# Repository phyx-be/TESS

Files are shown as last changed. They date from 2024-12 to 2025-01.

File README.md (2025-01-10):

# TESS
## TESS
TESS is an Adafruit Feather compatible embedded Linux board based on the Allwinner T113-S3 SoC with 128MB of DDR3 RAM built-in. We did add some pins that are not in the original spec, these allow for USB and debug UART to be available on regular pinheaders. This SoC does however only have 1 ADC pin availble that is even limited to 1.8V, so the extra analog pins are replaced by digital pins with various mux options. Allowing for multiple I²C busses, UARTs and CAN interfaces to be used.
Some key features of TESS REV 00 are:
- [Allwinner T113-S3 SoC](https://linux-sunxi.org/T113-s3) with dual core Cortex A7 running at 1.2GHz and 128 MB DDR3 RAM
- 512 MB SD-storage soldered down
- [ESP32-C3-MINI-1](https://www.espressif.com/en/module/esp32-c3-mini-1-en) Wi-Fi and Bluetooth module
- battery charger (up to 1.2A selectable in software)
- Microphone
- 3 user LEDs
- [RPI Touch Display 2](https://www.raspberrypi.com/products/touch-display-2/) compatible DSI connector

## Software
Follow the development of our [buildroot Linux.](https://github.com/phyx-be/buildroot-tess)

## Blockdiagram
TESS is designed to be a breakout board for the Allwinner T113-S3 with limited features on the board but maximal flexibility.
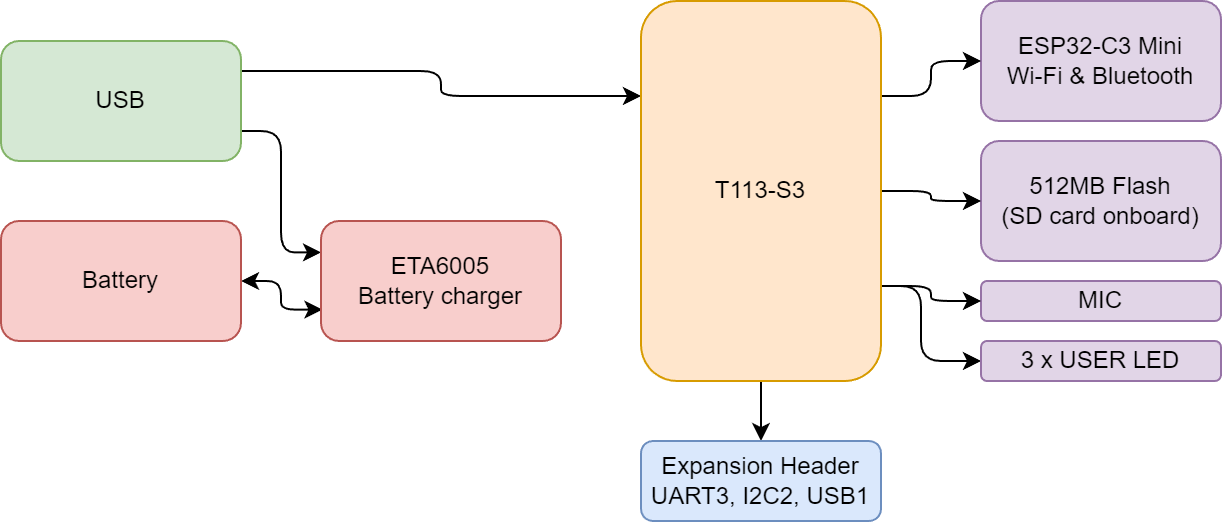
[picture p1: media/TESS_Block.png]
TESS 00 Blockdiagram


## Power
TESS has a 3.3V and 0.9V DC-DC regulator onboard whilst the T113-S3 has 2 LDO's built-in for the 1.8V and 1.5V rails.
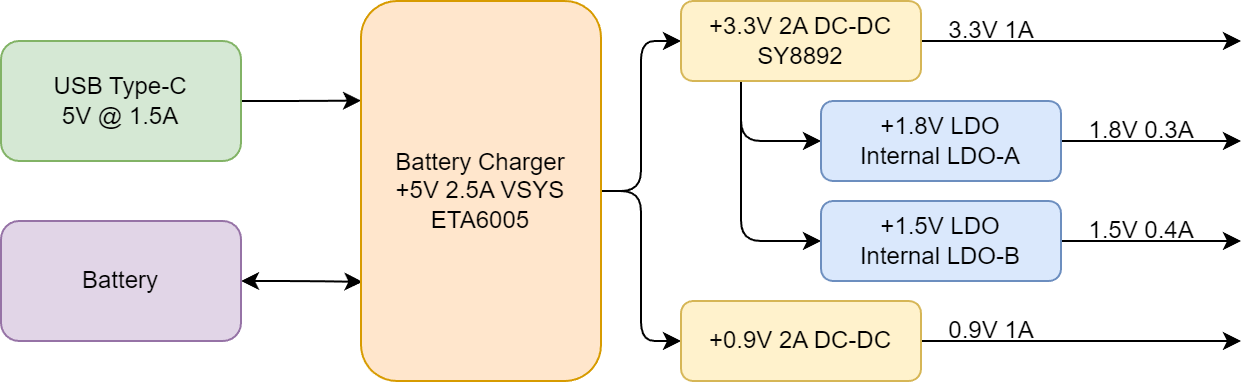
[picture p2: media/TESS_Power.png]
TESS 00 pinout


## Pinout
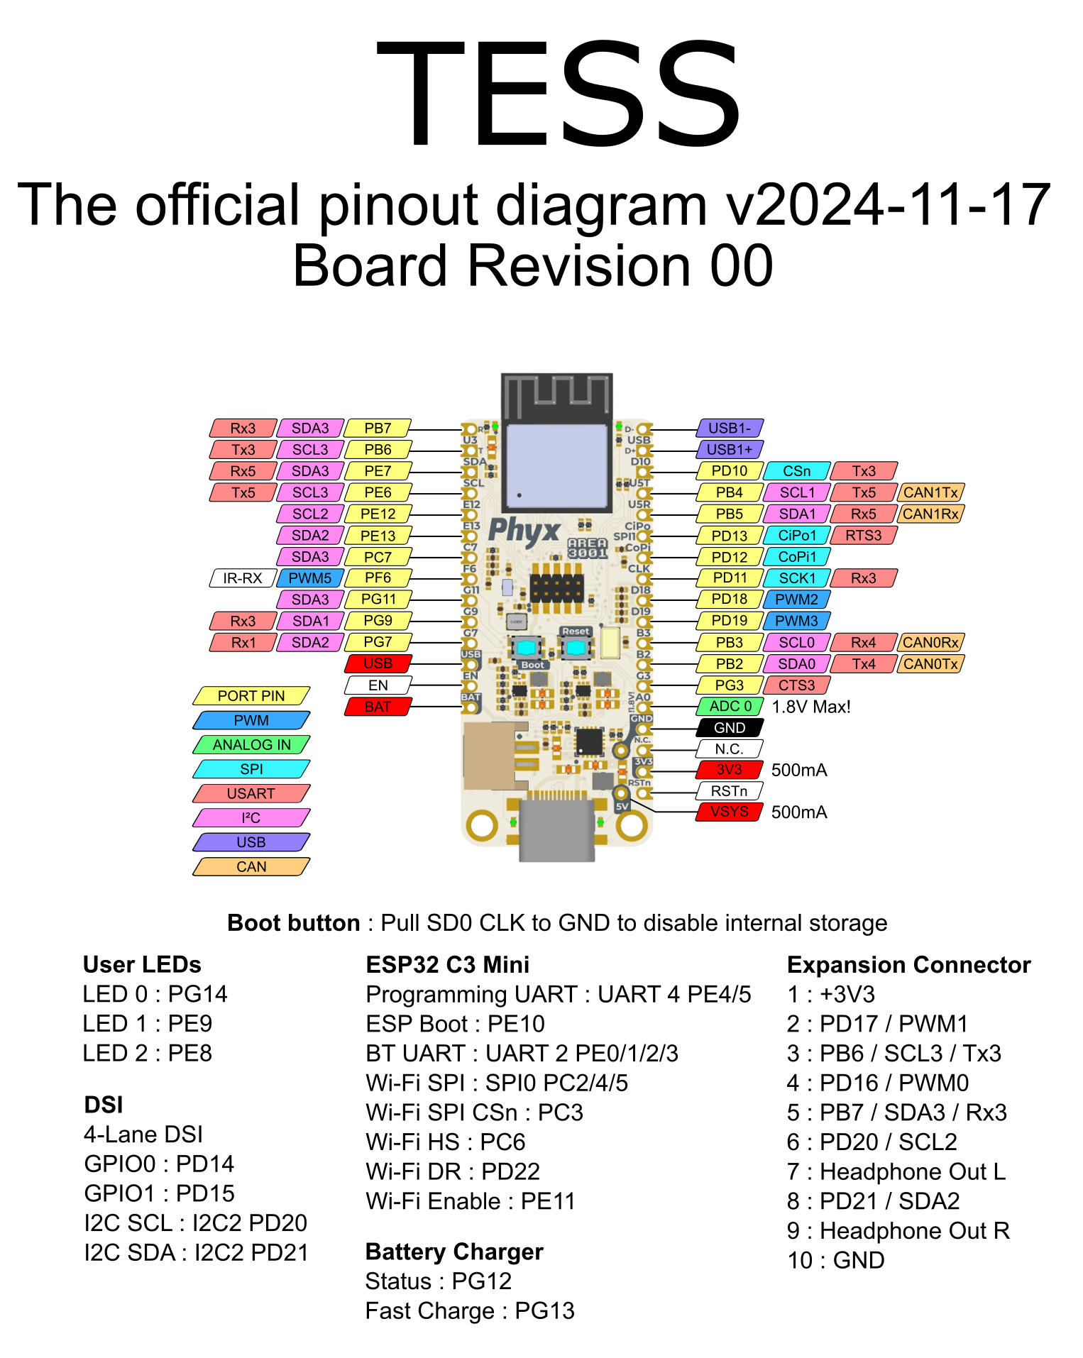
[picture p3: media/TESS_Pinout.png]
TESS 00 pinout


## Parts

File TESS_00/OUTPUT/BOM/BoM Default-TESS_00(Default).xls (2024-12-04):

Bill of Materials |  |  | Tess
Project: |  | TESS_00.PrjPcb
Revision: |  | 00
Variant: |  | Default
Creation Date: | 13/11/2024 | 21:49
Print Date: | 2024-11-15 | 11:54:10
Footprint | Comment | LibRef | Designator | Value | Description | Supplier 1 | Supplier Part Number 1 | Supplier 2 | Supplier Part Number 2 | Supplier 3 | Supplier Part Number 3 | Quantity
C0402 |  | CAP # 10pF 50V 0402 | C1, C2, C3, C4, C41, C42 | 10pF | CAP # 10pF 50V 0402 |  |  |  |  | Generic | 10pF 0402 | 6
C0603_N |  | CAP # 22uF 6.3V 0603 X5R | C5, C31, C34, C35, C38, C39, C43, C44, C45, C46 | 22uF 6V3 | CAP # 22uF 6.3V 0603 X5R | LCSC | C6119880 | LCSC | C159801 | LCSC | C59461 | 10
C0402 |  | CAP # 100nF 50V 0402 | C6, C7, C8, C9, C12, C13, C16, C17, C18, C19, C20, C25, C26, C27, C28, C29, C32, C36, C40, C48, C49, C50, C51, C52, C53, C59, C60 | 100nF 50V | CAP # 100nF 50V 0402 | Farnell | 3013345 | LCSC | C131394 | Generic | 100nF 50V 0402 X7R | 27
C0402 |  | CAP # 10uF 6V3 0402 | C10, C22, C30, C33, C37, C47 | 10uF 6V3 | CAP # 10uF 6V3 0402 | LCSC | C15525 | LCSC | C87148 | Generic | 10uF 6V3 0402 X5R | 6
C0402 |  | CAP # 2u2F 6V3 0402 | C11, C14, C15, C23, C24 | 2u2F 6V3 | CAP # 2u2F 6V3 0402 | LCSC | C12530 |  |  | Generic | 2u2F 6V3 0402 X5R | 5
C0402 |  | CAP # 1uF 10V 0402 | C21 | 1uF 10V | CAP # 1uF 10V 0402 | LCSC | C380293 |  |  | Generic | 1uF 10V 0402 X5R | 1
LED_0402_GR | Default 0402 Green LED | LED # Green 0402 | D1, D2, D3, D4 |  | LED # Green 0402 | LCSC | C434449 | LCSC | C25503345 |  |  | 4
XUNPU-TYPEC-304S-ACP16 | USB 2.0 C Reversible Receptacle Horizontal full SMD | USB # C 2.0 RCPT TYPEC-304S-ACP16 | J1 | TYPEC-304S-ACP16 | USB # C 2.0 RCPT TYPEC-304S-ACP16 | LCSC | C5187472 | LCSC | C2927040 | LCSC | C5156603 | 1
SUN_0806 | WPN201610H1R0MTY01 | IND # 2u2H 2.2A WPN201610H1R0MTY01 0806 | L1, L2 | 2u2H | IND # 2u2H 2.2A WPN201610H1R0MTY01 0806 | LCSC | C97003 |  |  |  |  | 2
SUN_1008 | WPN252012H2R2MT | IND # 2u2H 1.9A WPN252012H2R2MT 1008 | L3 | 2u2H | IND # 2u2H 1.9A WPN252012H2R2MT 1008 | LCSC | C98350 |  |  |  |  | 1
ESP-ESP32-Cx-MINI-1 | ESP32-C3 based MINI-1 4MB Flash | WiFi # MOD ESP32-C3-MINI-1-N4 | MOD1 | ESP32-C3-MINI-1-N4 | WiFi # MOD ESP32-C3-MINI-1-N4 | LCSC | C2838502 | Digi-key | 1965-ESP32-C3-MINI-1-N4CT-ND |  |  | 1
WE_620102131822 | Header 2.0mm Shrouded 2 | HDR # SHR 2.0mm 2way - 620102131822 | P1 | 620102131822 | HDR # SHR 2.0mm 2way - 620102131822 | Wurth | 620102131822 | Mouser | 710-620102131822 |  | C2888424 | 1
JUS_FC05-S22DCU-00 | 22 way 0.5mm Horizontal Top Contact ZIF | ZIF # 0.5mm H Top 22 way - FC05-S22DCU-00 | P4 | FC05-S22DCU-00 | ZIF # 0.5mm H Top 22 way - FC05-S22DCU-00 | LCSC | C2998855 | LCSC | C11091 |  |  | 1
HDR2X5_1.27_SMD | Header 5x2 | Pin Header # 1.27mm dual row 10way | P5 |  | Pin Header # 1.27mm dual row 10way | Farnell | 1022310 | Wurth | 621 010 210 21 |  |  | 1
R0402 |  | RES # 5K1 0402 | R1, R2 | 5K1 | RES # 5K1 0402 | LCSC | C274895 |  |  | Generic | 5K1 1% 0402 | 2
R0402 |  | RES # 100K 0402 | R3, R10, R13, R18, R19, R29 | 100K | RES # 100K 0402 | Farnell | 1358096 |  |  | Generic | 100K 1% 0402 | 6
R0402 |  | RES # 4K7 0402 | R4, R5, R6, R7, R8, R9, R11, R12, R23, R24, R33, R35, R36, R38, R39 | 4K7 | RES # 4K7 0402 |  |  |  |  | Generic | 4K7 1% 0402 | 15
R0402 |  | RES # 10K 0402 | R14, R20, R21, R22, R25, R28, R37 | 10K | RES # 10K 0402 | Farnell | 1358069 |  |  | Generic | 10K 1% 0402 | 7
R0402 |  | RES # 2K2 0402 | R15, R27 | 2K2 | RES # 2K2 0402 |  |  |  |  | Generic | 2K2 1% 0402 | 2
R0402 |  | RES # 22R 0402 | R16 | 22R | RES # 22R 0402 | Farnell | 1357998 |  |  | Generic | 22R 1% 0402 | 1
R0402 |  | RES # 0R 0402 | R17 | 0R | RES # 0R 0402 | Farnell | 2072513 |  |  | Generic | 0R 1% 0402 | 1
R0402 |  | RES # 820R 0402 | R26 | 820R | RES # 820R 0402 |  |  |  |  | Generic | 820R 1% 0402 | 1
R0402 |  | RES # 240R 0402 | R30, R40 | 240R | RES # 240R 0402 | LCSC | C114755 | LCSC | C25094 | Generic | 240R 1% 0402 | 2
R0402 |  | RES # 75R 0402 | R31 | 75R | RES # 75R 0402 | LCSC | C103159 | LCSC | C168249 | Generic | 75R 1% 0402 | 1
R0402 |  | RES # 33R 0402 | R32, R34 | 33R | RES # 33R 0402 |  |  |  |  | Generic | 33R 1% 0402 | 2
WE_434153017835 | LP SMD tact sw WS-TASV | SW # TACT mini 3.5x2.9 mm SMD J-Bend WS-TASV | SW1, SW2 | 434153017835 | SW # TACT mini 3.5x2.9 mm SMD J-Bend WS-TASV | Wurth | 434153017835 | Mouser | 710-434153017835 | LCSC | C33129656 | 2
TQFP_128_14.0x14.0_P0.4_5.7x5.7EP | 2 x A7 1GHz, 128MB DDR3 | A7 # T113-S3 | U1 | T113-S3 | A7 # T113-S3 | LCSC | C5197687 |  |  |  |  | 1
ZET_LGA8 | SD Card chip 2.7V~3.6V 4Gbit LGA-8(6x8) NAND FLASH | FLSH SD # 4Gb ZDSD04GLGEAG | U2 | ZDSD04GLGEAG | FLSH SD # 4Gb ZDSD04GLGEAG | LCSC | C2875854 | LCSC | C5349318 |  |  | 1
SIL_SOT563 | 2.5~5.5Vin 2A SOT563 SY8892 | PWR # BUCK SY8892 2A | U3, U4 | SY8892 | PWR # BUCK SY8892 2A | LCSC | C3151908 |  |  |  |  | 2
QFN_16_3X3_P0.5_1.65X1.65EP | 2.5A 3MHz DCDC Li-Ion charger | PWR # BOOST CHG 2.5A ETA6005Q3Q | U5 | ETA6005Q3Q | PWR # BOOST CHG 2.5A ETA6005Q3Q | LCSC | C7436030 |  |  |  |  | 1
LIN_LMA3722T421-OA5 | Omni-directional -42dB 300Ω 55dB SMD-4P,3.8x2.2mm MEMS Microphones | MIC # MEMS ANA LMA3722T421-OA5 | U6 | LMA3722T421-OA5 | MIC # MEMS ANA LMA3722T421-OA5 | LCSC | C5373233 |  |  |  |  | 1
XTAL_2012 | 32.768Khz 2012 12.5pF | XTAL # 32.768kHz 12.5pF 2012 | Y1 | 32.768kHz | XTAL # 32.768kHz 12.5pF 2012 | LCSC | C5271201 | LCSC | C97607 | LCSC | C403709 | 1
XTAL_2520 | 24MHz 2520 9pF 10ppm | XTAL # 24MHz 9pF 2520 10ppm | Y2 | 24MHz | XTAL # 24MHz 9pF 2520 10ppm | LCSC | C7294625 |  |  |  |  | 1
 |  |  |  |  |  |  |  |  |  |  |  | 117
Approved |  | Notes

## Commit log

2026-11-11 Add the Buildroot external tree
    buildroot-external/ is the BR2_EXTERNAL tree for the Tess images: the
    A/B main image with RAUC (tess_defconfig), the USB flasher image
    (tess_flasher_defconfig), the board files and the ESP32-C3 firmware
    build. It builds on the phyxbe-tess branch of
    https://github.com/phyx-be/buildroot-tess, which adds the board
    support (device tree, U-Boot fragment, minimal defconfig) meant for
    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
2026-11-11 buildroot-external: U-Boot default environment file, merged overlays, common fragment
    - The A/B boot environment of the main image is no longer a U-Boot
    patch (board/sunxi/tess.env through CONFIG_ENV_SOURCE_FILE) but the
    text file board/tess/uboot/tess-main.env, used as the complete default
    environment with BR2_TARGET_UBOOT_DEFAULT_ENV_FILE. As that replaces
    the whole built-in environment, the file also carries bootcmd and the
    sunxi load addresses that sysboot/extlinux need.
    - The root filesystem overlays move under board/tess/rootfs_overlay/:
    common (both images), main and flasher.
    - The U-Boot fragment shared by both images (device tree overlays) is
    board/tess/uboot/tess-comm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
2026-11-11 buildroot-external: build the display overlay as a .dtb, drop the kbuild patch
    Linux 6.18 cannot build a single .dtbo in arch/arm/boot/dts, where
    Buildroot copies custom device trees: that directory has no dtb-y, so
    kbuild does not include the %.dtbo rule. Instead of patching kbuild,
    name the overlay source rpi-7inch-dsi-overlay.dts and let the kernel
    build it with its %.dtb rule; the result, rpi-7inch-dsi-overlay.dtb,
    is an overlay all the same (checked: __symbols__ and __fixups__
    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
2026-11-11 buildroot-external: Buildroot as a git submodule
    buildroot-external/buildroot is a submodule of the phyxbe-tess branch of
    https://github.com/phyx-be/buildroot-tess, pinned to the commit that
    adds the board support, instead of a checkout the user has to create.
    The READMEs explain cloning with submodules and moving the submodule
    after a rebase of the branch.
2026-11-11 buildroot-external: take the kernel and U-Boot hashes from the in-tree board directory
    BR2_GLOBAL_PATCH_DIR lists Buildroot's board/phyxbe/tess/patches before
    the external patch directory, so the hash files of Linux 6.18.8, its
    headers and U-Boot 2026.01 that the board support commit carries are
    used, and the copies here go. Buildroot looks for
    <dir>/<package>/<package>.hash in every global patch directory.
2026-11-11 buildroot-external: make targets for both images and flashing, flash.sh at the top
    external.mk gets tess-main, tess-flasher (builds the main image first,
    as the flasher embeds it) and tess-flash, usable from any configured
    output directory: make -C output-flasher tess-flasher. tess-flash first
    runs sunxi-fel version to check that the board is in FEL. flash.sh, a
    host tool rather than a board file, moves to the top of the tree.
2026-11-11 buildroot-external: kernel fragments in board/tess/linux/
    Kernel configurations are checked to come out identical.
2026-11-11 buildroot-external: flasher on the USB serial console, like the main image
    Nothing in the flasher used its CDC ECM + RNDIS network gadget: it is
    driven from a console. Both images now use the CDC ACM serial gadget
    with a login console on ttyGS0 (usb-getty and the inittab entry move to
    the common overlay and post-build.sh), so tess-install needs no UART
    adapter. The ethernet gadget fragment, the bridge and its init script
    go, and the flasher, which has no network at all, loses dnsmasq and
    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
2026-11-11 buildroot-external: top-level Makefile with main, flasher and flash targets
    make flasher builds the main image and then the flasher image that
    embeds it, make main only the first, make flash boots the flasher over
    FEL after checking with sunxi-fel that the board is there, and make
    main-<target> / flasher-<target> run any Buildroot target in one build.
    An output directory without a configuration gets its defconfig. This
    replaces the targets in external.mk, which needed a configured output
    directory to be reachable.
2026-11-11 buildroot-external: Makefile: esp32c3 target for the ESP32-C3 firmware
    make esp32c3 runs board/tess/esp32c3/build.sh with the Buildroot tree
    and the main build's output directory, so the firmware comes from the
    esp-hosted-linux commit of the esp-hosted package.
2026-11-11 buildroot-external: esp32c3/ at the top of the tree
    The ESP32-C3 firmware build is not a Buildroot board file; its output
    still goes to the flasher overlay.
2026-11-11 buildroot-external: ESP32-C3 firmware out of git, copied into the flasher at build time
    esp32c3/build.sh writes the firmware to output-esp32c3/ (TESS_ESP32C3_O,
    not tracked) instead of the flasher overlay, and
    board/tess/post-build-flasher.sh checks its SHA256SUMS and installs it
    in /lib/firmware/esp-hosted/ of the flasher image, failing with a hint
    when make esp32c3 has not run. The committed NG-1.0.6.0.15 binaries go.
2026-11-11 buildroot-external: drop the superseded ESP32-C3 firmware patch 0002
    esp-hosted-linux 54d5367 tags the DISCONNECT event with the generation
    of the disconnect command (s_disconnect_generation), so the host accepts
    the late event that the patch made immediate. The patch no longer
    applied there; the reconnect after wpa_cli disconnect is to be
    re-checked on the board.
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2026-11-11 buildroot-external: ask Buildroot for the esp-hosted version and tarball
    esp32c3/build.sh gets ESP_HOSTED_VERSION, ESP_HOSTED_DL_DIR and
    ESP_HOSTED_SOURCE with make printvars from the configured main build
    instead of parsing esp-hosted.mk and assuming the tarball name and the
    download directory. make esp32c3 configures the main build first when
    needed.
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2026-11-12 buildroot-external: no display in the flasher, network files in the main overlay
    The flasher runs from the USB console and has no use for the display:
    it loses the display and framebuffer console kernel fragments, the DSI
    overlay and device tree overlay support, and console=tty0, fbcon and the
    overlay in its boot script and flash.sh. U-Boot overlay support, the only
    content of tess-common.fragment, is main-image only now and moves into
    tess-main.fragment.
    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
2026-11-12 buildroot-external: write the SD NAND over USB DFU, flasher only for the ESP32-C3
    The flasher's U-Boot gets the sunxi MUSB gadget, DFU over USB with the
    MMC back end and dfu-util as a host tool (tess-flasher.fragment), and a
    default environment (tess-flasher.env) whose bootcmd looks at
    fel_scriptaddr, which U-Boot's sunxi code sets only when sunxi-fel
    uploaded a boot script along with U-Boot:
    - flash.sh does, so U-Boot boots the flasher Linux as before;
    - flash-sd.sh starts U-Boot alone, so it runs "dfu 0 mmc 0" with the
    whole SD NAND as the raw "sdcard" entity, and resets the board when
    dfu-util detaches.
    flash-sd.sh (make flash-sd [IMAGE=...]) checks the board is in FEL,
    starts U-Boo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
2026-11-12 buildroot-external: trim the flasher to what it uses
    The flasher's scripts only call espflash, gpioset and busybox applets
    from Buildroot's default busybox configuration. It loses e2fsprogs,
    iproute2, ca-certificates, evtest, host-e2fsprogs, C++ in the toolchain,
    the busybox fragment and the option to override busybox applets (and so
    ifplugd and its init script). busybox.frag is main-image only now.
    Checked with a clean flasher build: root filesystem 11.3 MB to 9.2 MB,
    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
2026-11-12 buildroot: update to e728256
    phyxbe-tess was squashed back into a single commit for the pull request
    (the device tree fixup 951b39f folded into the board support commit);
    the files are the same.
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
